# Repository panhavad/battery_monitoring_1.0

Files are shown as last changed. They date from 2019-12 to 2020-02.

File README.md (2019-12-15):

# Battery Monitoring 1.0 for Network's Antenna

In order to get internet connection to supply the whole vKirirom resort, network department is totally dependent on internet signal received by an antenna placed on the top of the mountain which can not supply electricity there by wire. So network department decided to use solar panel and battery but there were certain problem that cause the lost of internet supply to vKirirom such as Battery is empty without knowing. So this project is created to solve that problem by monitoring the battery power remotely.

**During the initial creation of the Network Battery Monitoring V1.0 we are targeting a specific goal to achieve in this version such as:**
1. Live monitoring of each battery power
2. Alert to the responsible person when the battery power reaches a certain level
3. Able to transfer battery information through ethernet
4. 60% of the programming configuration should be able to customize through network.

Finally, after all the hard work, and the help from network department team. I am able to understand what the problem is, what they need, and what are all the constraints I have to handle during do the project. On 12 October 2019 Network Battery Monitoring V1.0 was indoor tested and satisfy by Mr.Nget Phanny.

Yours Truly,
Duk Panhavad

### Hardware usage

- Arduino UNO (Chiness Version)
- Arduino Ethernet Shield W5100
- Customize Series Voltage Divider

## Series Voltage Divider Schema
Series Voltage Divider Schema

## Whole Circuit Connection
Whole Circuit Connection

## Case Modeling
Case Modeling

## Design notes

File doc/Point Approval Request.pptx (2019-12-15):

## Network’s Battery Monitoring

Dexpertize Virtual Company

## Problems

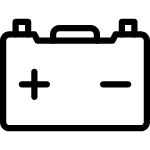
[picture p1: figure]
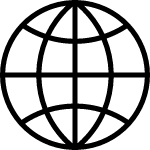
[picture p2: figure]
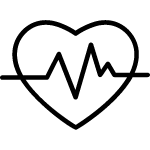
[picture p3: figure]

Running out of battery without knowing

Increase internet downtime

Battery health is unknown

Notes: Running out of battery without knowing
Increase internet down time
Battery health is unknown (identify the infection)

## Solutions / Objectives

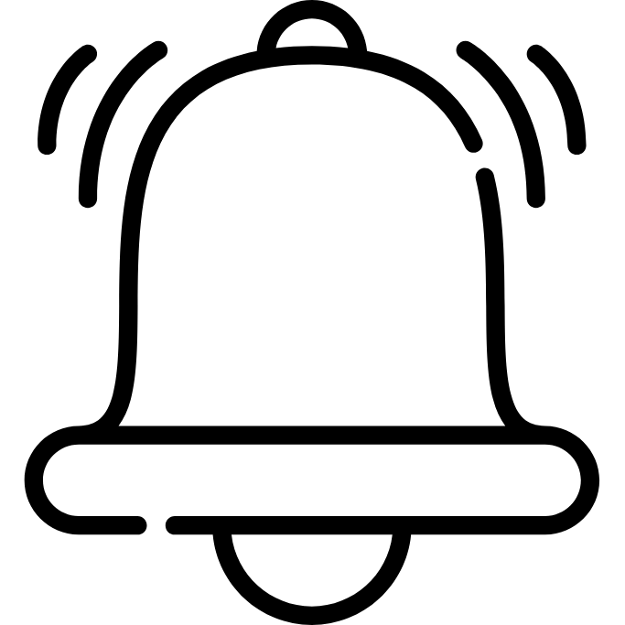
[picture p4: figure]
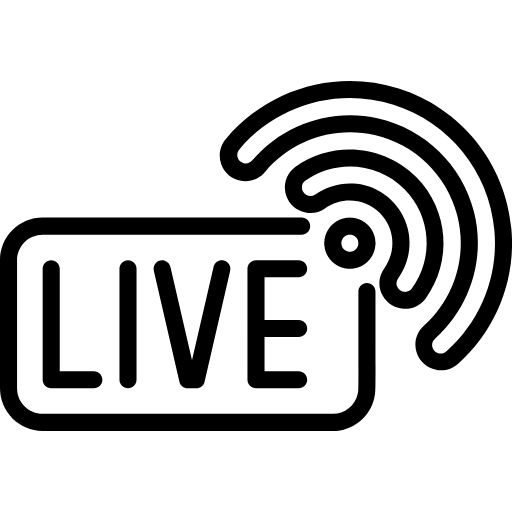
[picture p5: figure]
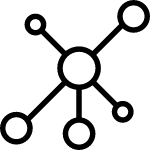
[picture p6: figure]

Notify when battery running low

Live monitor battery Voltage

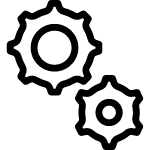
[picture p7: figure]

Work within local-network

Threshold & Alert Interval Configuration can done on app/web

## Output (Software)

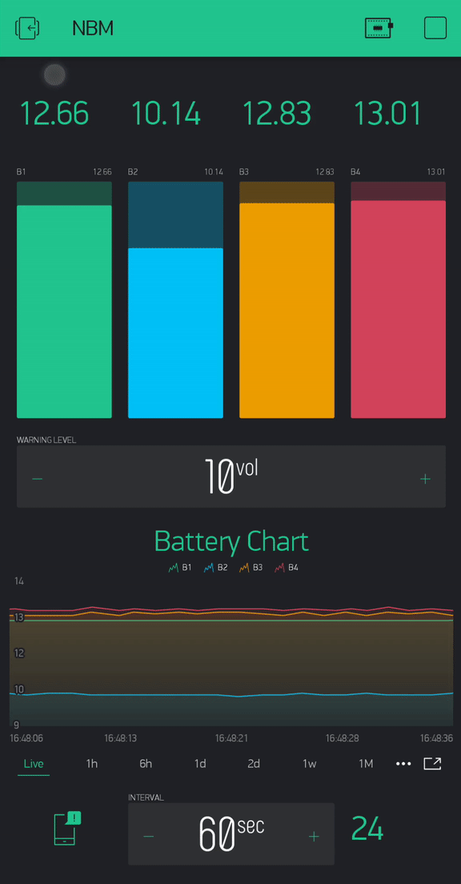
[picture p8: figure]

Live monitor battery Voltage

Voltage Threshold for alert

Battery voltage histogram

Alert interval in second

## Output (Software)

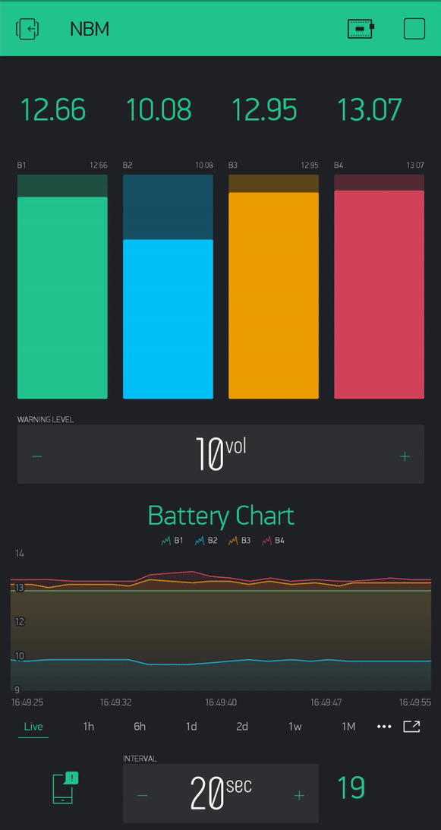
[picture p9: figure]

Alert / Notification when battery reach threshold

## Output (Hardware)

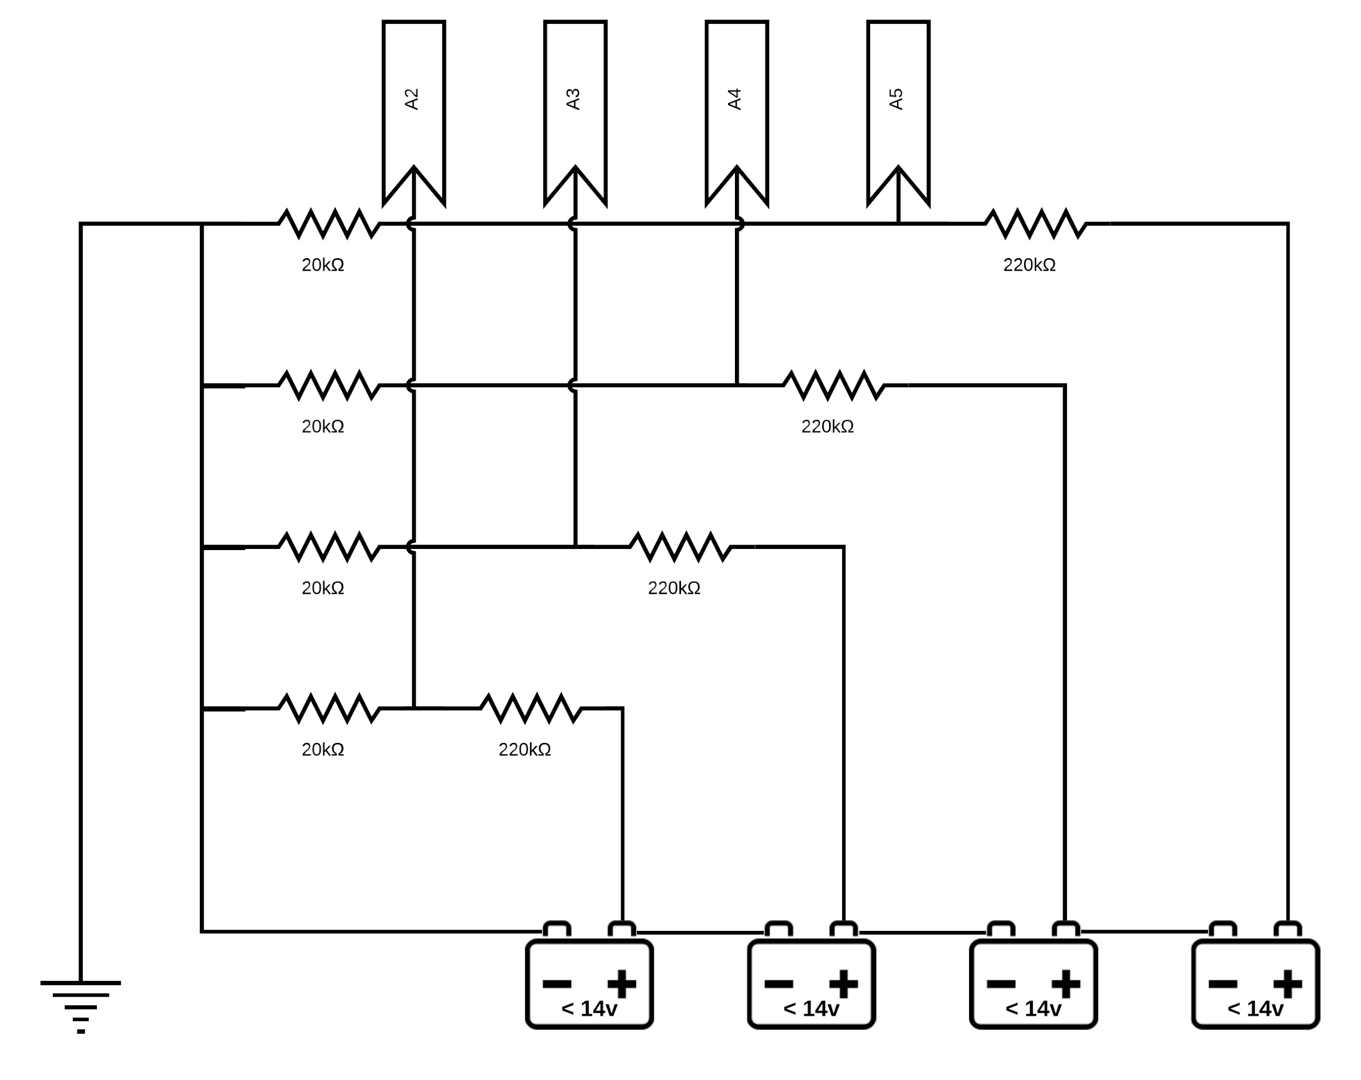
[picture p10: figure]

Voltage divider for Series of battery

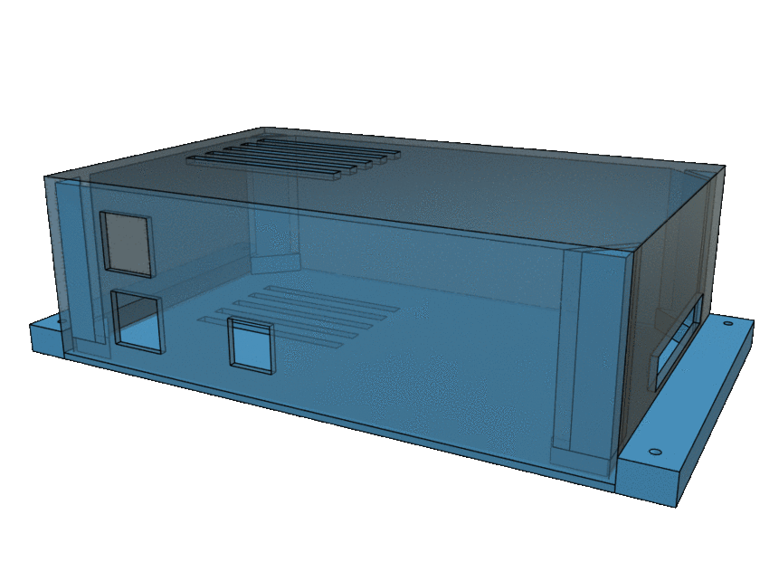
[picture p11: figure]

3D Printed Case (KIT)

## Cost of Production

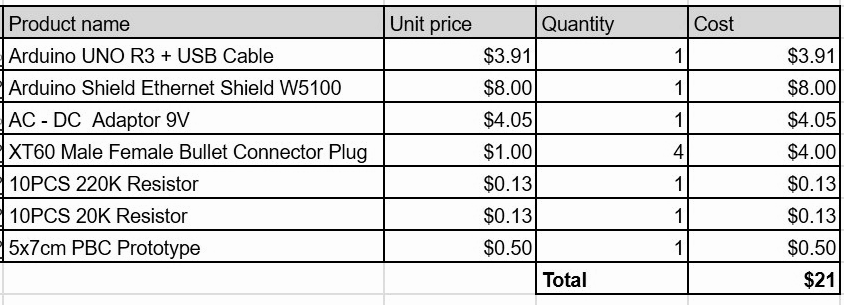
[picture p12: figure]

## Demo

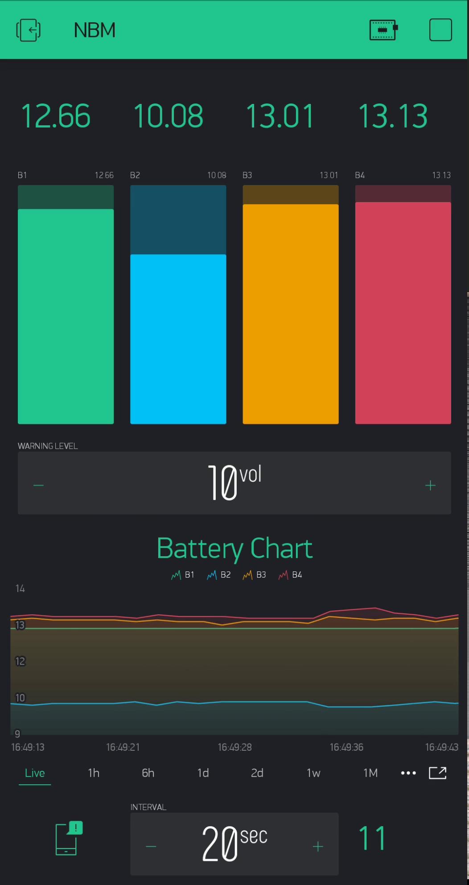
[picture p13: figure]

## Mr.Takeshi Remark

This project is successfully closed and approve 10 KIT Point

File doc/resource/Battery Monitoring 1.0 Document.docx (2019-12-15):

# Network Battery Monitoring(NBM) Document

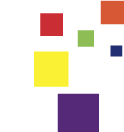
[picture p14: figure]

# Version 1.0

### DEVELOPED BY

DUK PANHAVAD (BATCH3)

# Table of Contents

Introduction 3

Document Purpose 3

Scope of document 3

Definitions, acronyms, and abbreviations 3

References Document 3

Hardware overview 4

Hardware usage 4

Voltage Divider Circuit 4

Hardware case 5

Software overview 6

Use-Case diagram 6

Cost of Production 7

Project Output 7

Network Battery Monitoring V1.0

JUN 27, 2019

### COMPANY - Dexpertize

### Projects - Network Battery Monitoring V1.0

Members:

Duk Panhavad

This is written to make understand of how this project created.

In order to get internet connection to supply the whole vKirirom resort, network department is totally dependent on internet signal received by an antenna placed on the top of the mountain which can not supply electricity there by wire. So network department decided to use solar panel and battery but there were certain problem that cause the lost of internet supply to vKirirom such as Battery is empty without knowing. So this project is created to solve that problem by monitoring the battery power remotely.

During the initial creation of the Network Battery Monitoring V1.0 we are targeting a specific goal to achieve in this version such as:

- Live monitoring of each battery power
- Alert to the responsible person when the battery power reaches a certain level
- Able to transfer battery information through ethernet
- 60% of the programming configuration should be able to customize through network.

Finally, after all the hard work, and the help from network department team. I am able to understand what the problem is, what they need, and what are all the constraints I have to handle during do the project. On 12 October 2019 Network Battery Monitoring V1.0 was indoor tested and satisfy by Mr.Nget Phanny.

Yours Truly,

Duk Panhavad

# 1. Introduction

This section gives a scope, description and overview of everything have to be done in this project.

## 1.1. Document Purpose

The purpose of this document is to give a detailed description of the requirements for the “Network Battery Monitoring”. It will illustrate the purpose and complete declaration for the development of system. It will also explain system constraints, interface and interactions with other external applications. This document is primarily intended to be a reference for developing the first version of the system for the developer.

## 1.2. Scope of document

From the very beginning, the lost of battery power at anata without knowing in advance cause so much problem to vKirirom Staff, Student, Customer and Security. So this project will be so helpful to solve those problems.

By notifying the responsible person in advance before those batteries run empty. This will be so useful for battery replacing problem since currently if the battery runs empty it might take nearly 3hours to prepare everything and fully replace those batteries.

While the responsible get notify in advance, any action that will have to perform in order to change the battery will be prepare in advance too. So this will bring vKirirom internet to 99.99% downtime.

## 1.3. Definitions, acronyms, and abbreviations

- NBM - Network Battery Monitoring
- Arduino UNO - is an open-source microcontroller board based on the Microchip ATmega328P microcontroller and developed by Arduino.cc
- Arduino Ethernet Shield - allows an Arduino board to connect to the internet
- Blynk - IoT platform to connect your devices to the cloud, design apps to control them, analyze telemetry data, and manage your deployed products at scale

## 1.4. References Document

- https://www.arduino.cc
- https://blynk.io

# 2. Hardware overview

## 2.1. Hardware usage

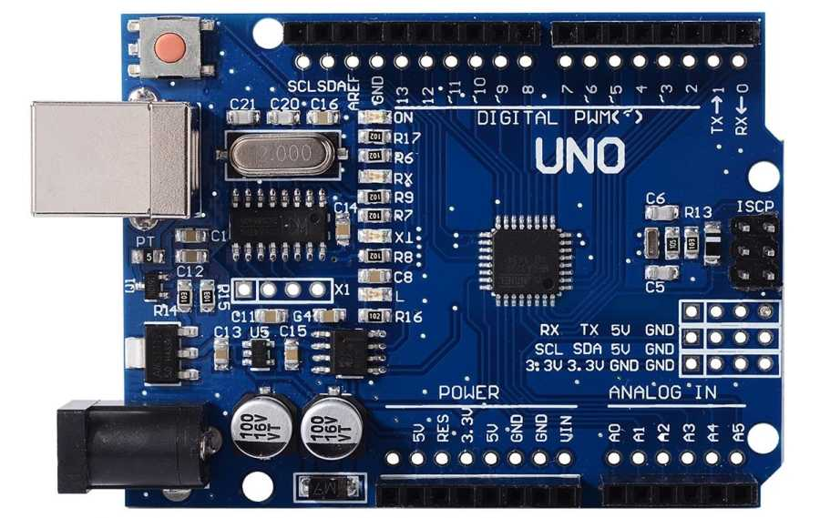
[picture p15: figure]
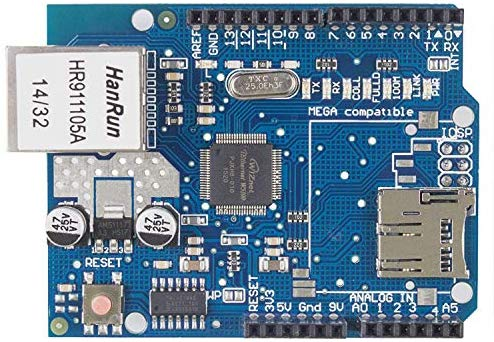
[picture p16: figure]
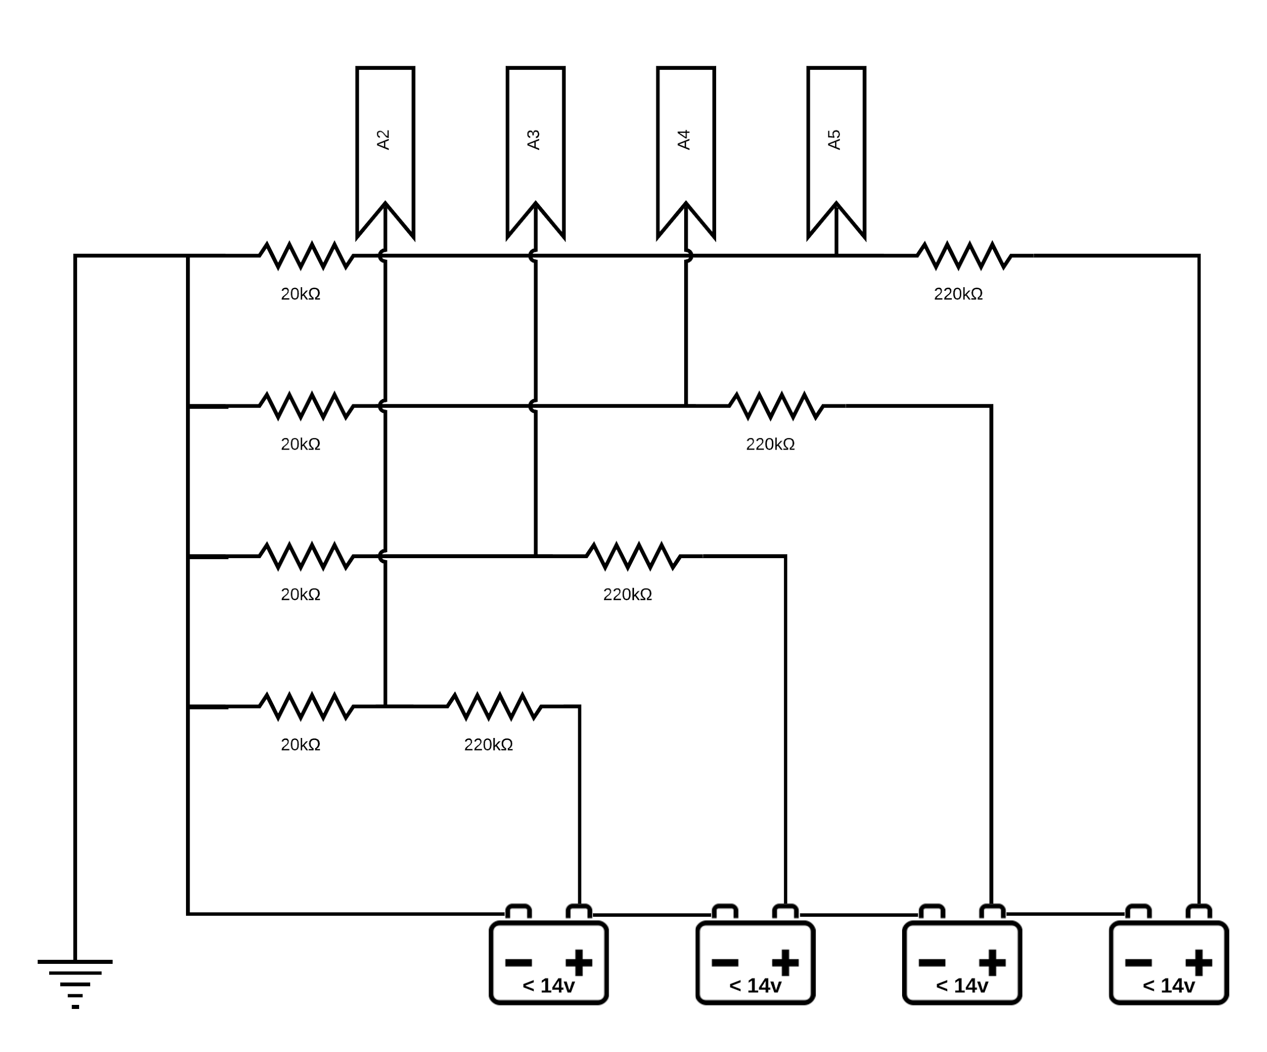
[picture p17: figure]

- Arduino UNO (Chiness Version)
- Arduino Ethernet Shield W5100
- Customize Series Voltage Divider

## 2.2. Voltage Divider Circuit

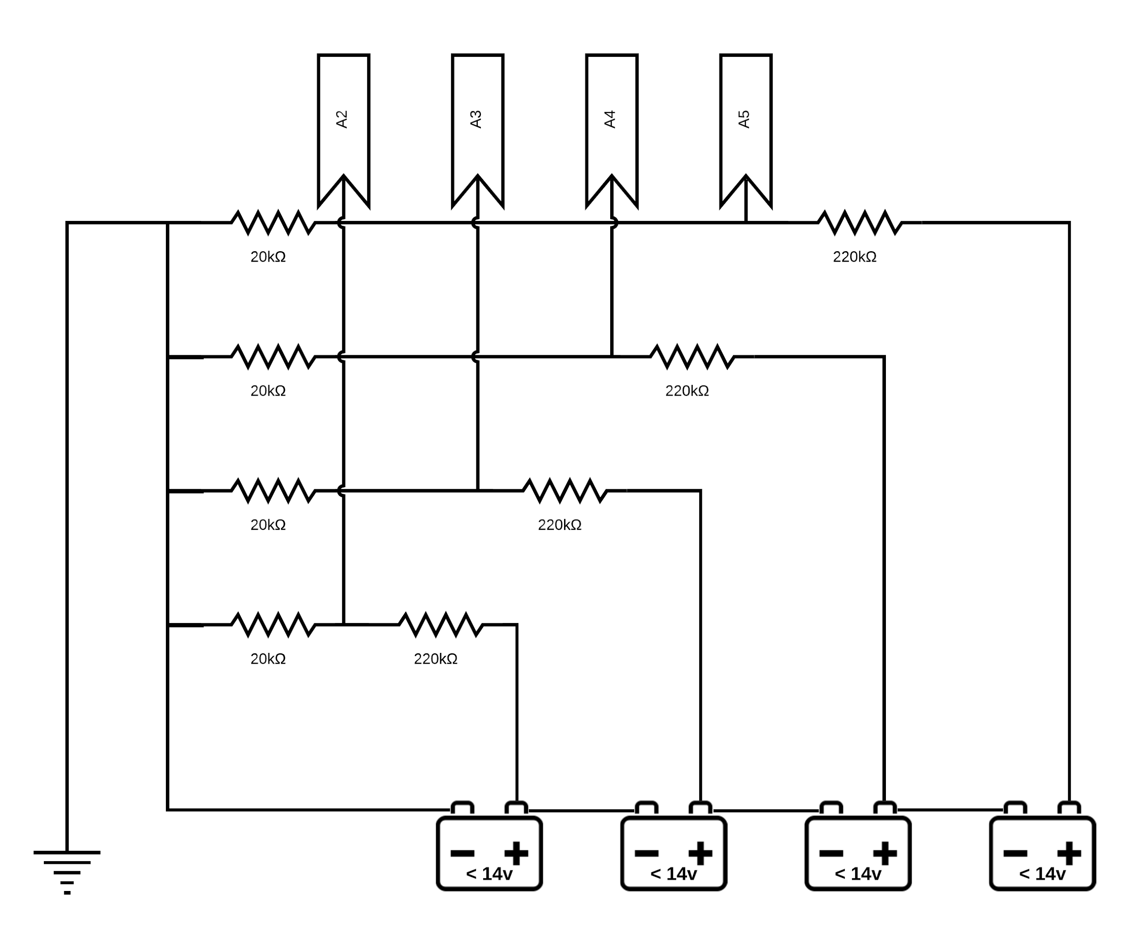
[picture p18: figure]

  2.3. Circuit Connection

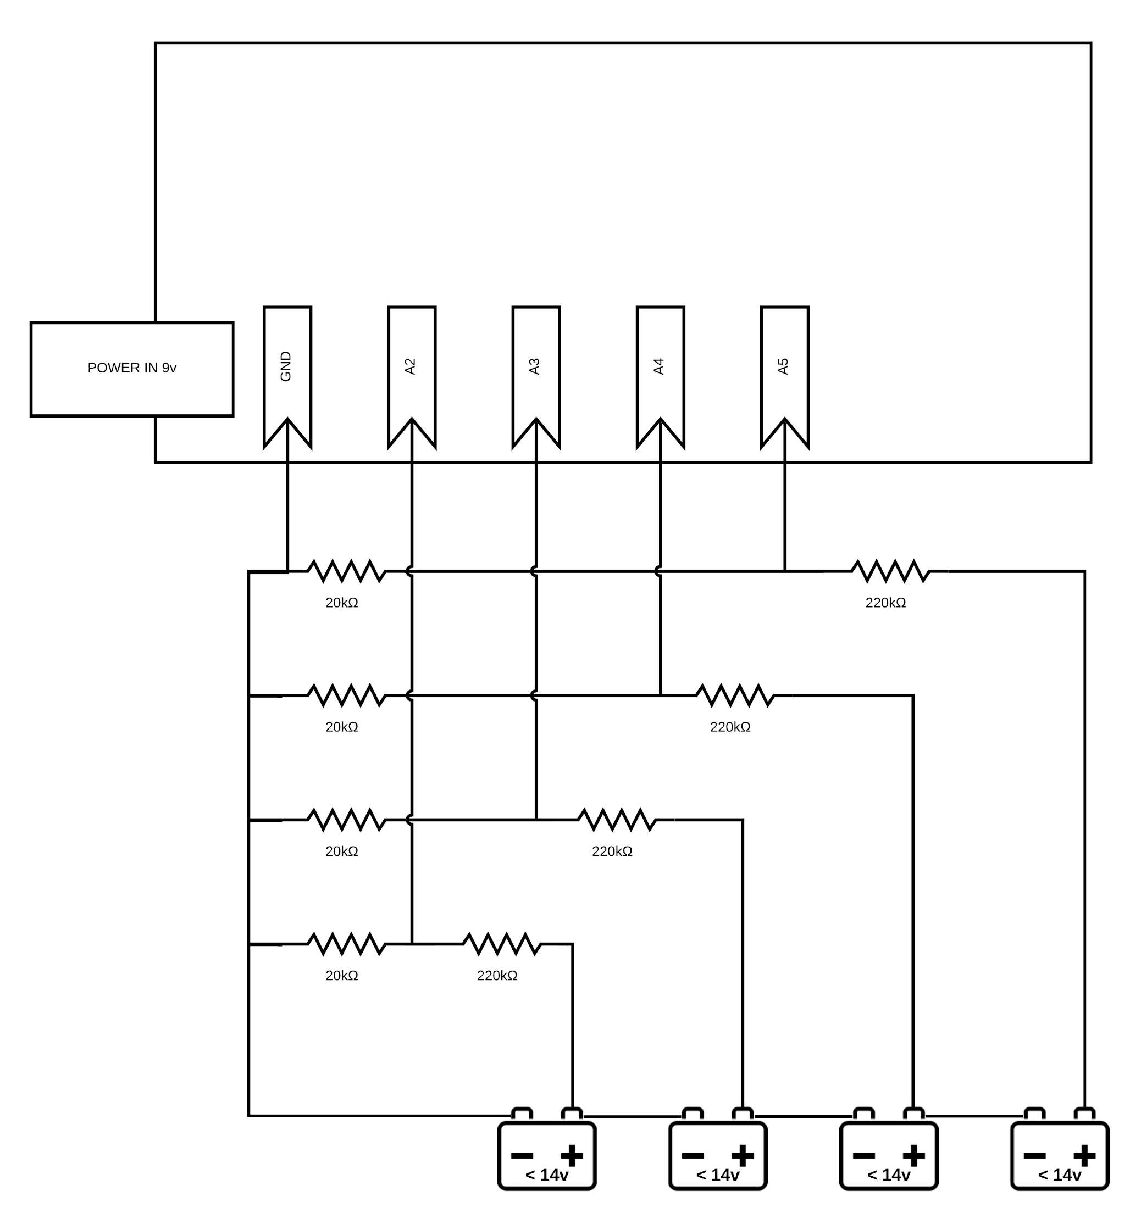
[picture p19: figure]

## 2.4. Hardware case

Link to 3D model: case_modeling (https://drive.google.com/drive/folders/1mzTB_Wjy93GVwVte1kKjALP6ZSL0zM3l)

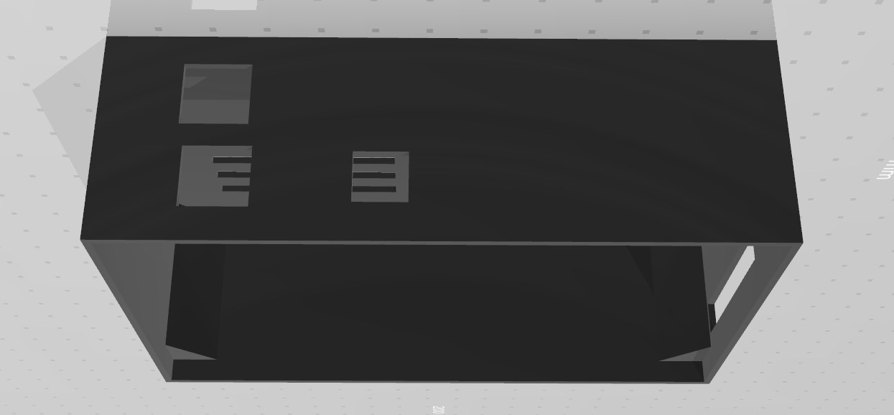
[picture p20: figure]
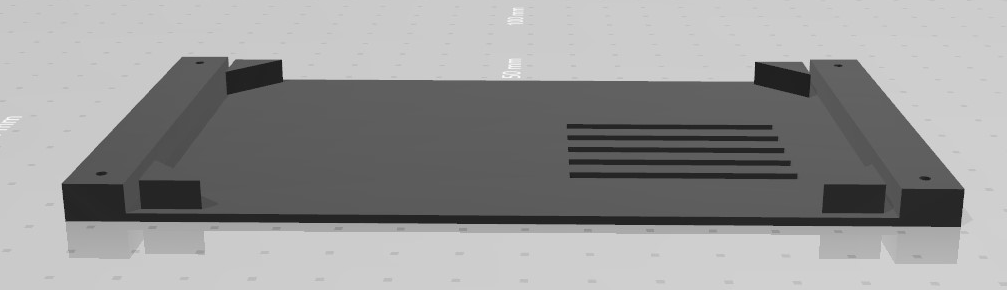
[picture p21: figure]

# 3. Software overview

  3.1. Software Usage

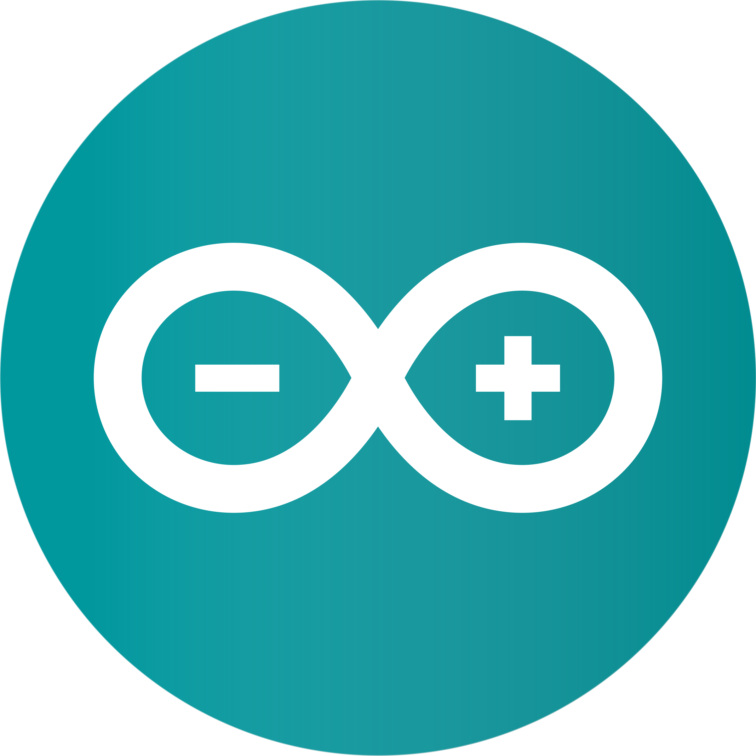
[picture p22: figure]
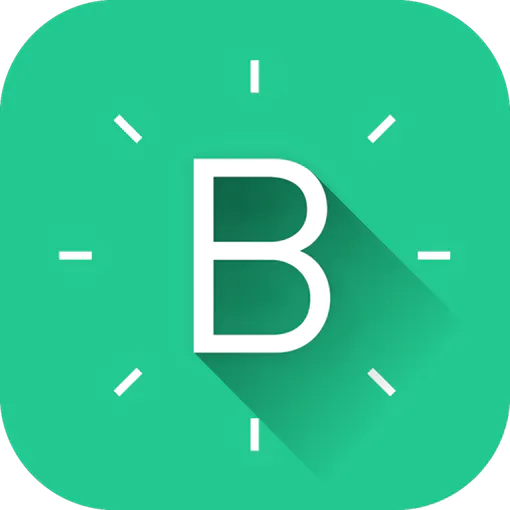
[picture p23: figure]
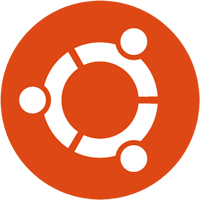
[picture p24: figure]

- Arduino IDE (Free)
- Blynk App (Free)
- Blynk Local Server (Free)

## 3.2. Use-Case diagram


  3.3. Source Code (Private)

Link to GitHub Repository: https://github.com/panhavad/network_battery_monitoring

# 4. Cost of Production


# 5. Project Output


Kirirom Institute of Technology Network Battery Monitoring 1.0

Kirirom Institute of Technology KIT Key Management System 1.0

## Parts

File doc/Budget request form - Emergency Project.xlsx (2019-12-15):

 | Budget Request Form
Company name: | Dexpertize
Project name: | Network Antenna Battery Monitoring
Project member: | Duk Panhavad
Request by: | Duk Panhavad
Reason of emergency: | The project is process during holiday, product is cheap, less quantity
Project Approve by: | Mr.Leo
Budget Approve by: | Mr.Leo
*NOTE: This document is use for request the budget, because project spend there own money to buy these listed product for the project. This is not request for purchase.
Link | Product name | Unit price | Quantity | Cost
https://www.aliexpress.com/item/32697443734.html | Arduino UNO R3 + USB Cable | $3.91 | 1 | $3.91
http://store.arrowdot.io/?product=arduino-shield-ethernet-shield-w5100 | Arduino Shield Ethernet Shield W5100 | $8.00 | 1 | $8.00
https://www.aliexpress.com/item/32961533195.html | AC - DC Adaptor 9V | $4.05 | 1 | $4.05
http://store.arrowdot.io/?product=xt60-male-female-bullet-connector-plug-for-lipo-battery-rc-drone | XT60 Male Female Bullet Connector Plug | $1.00 | 4 | $4.00
http://store.arrowdot.io/ | 10PCS 220K Resistor | $0.13 | 1 | $0.13
http://store.arrowdot.io/ | 10PCS 20K Resistor | $0.13 | 1 | $0.13
http://store.arrowdot.io/?product=5x7cm-single-side-diy-bakelite-prototype-circuit-pcb-board-tinned | 5x7cm PBC Prototype | $0.50 | 1 | $0.50
 |  |  | Total | $20.72

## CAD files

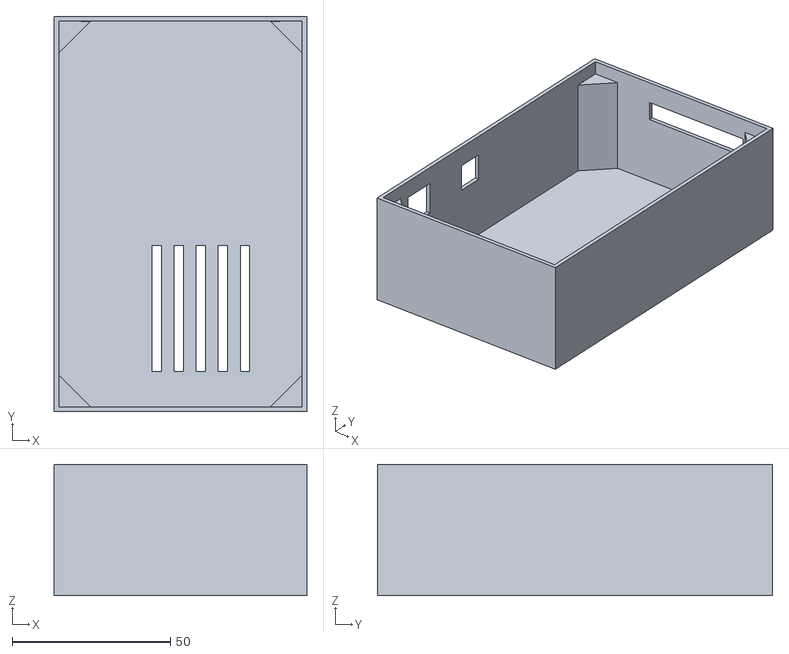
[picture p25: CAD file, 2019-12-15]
case_modeling/top.stl
80.0 x 125.0 x 41.5

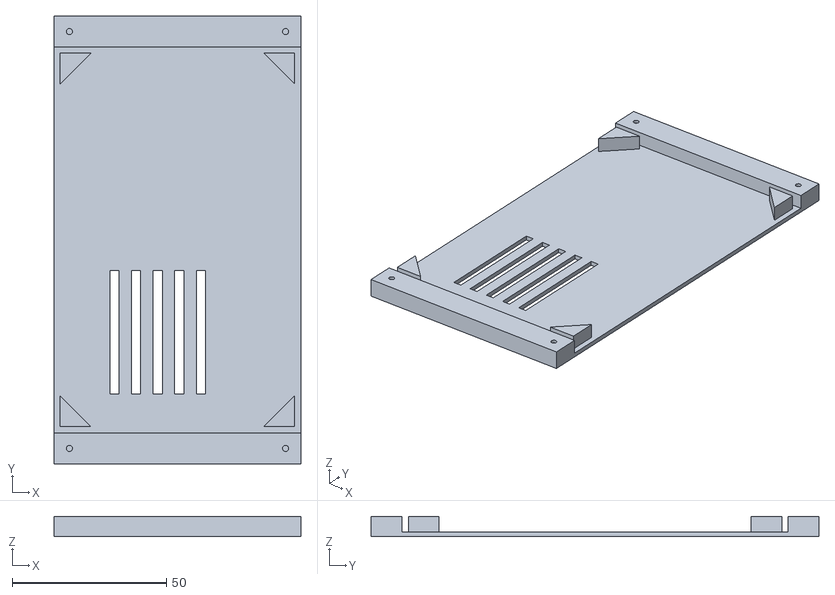
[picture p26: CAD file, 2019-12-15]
case_modeling/bottom.stl
80.0 x 145.0 x 6.50

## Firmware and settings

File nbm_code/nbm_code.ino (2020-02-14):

/////////////////////////
// AUTHOR : AHIRU SAN  //
// DATE : 01 NOVE 2019 //
/////////////////////////


//hardware related
#include <SPI.h> //library for ethernet shield
#include <Ethernet.h> //library for ethernet shield
#include <BlynkSimpleEthernet.h> //BLYNK communication using ethernet
#include <EEPROM.h> //memory that store data even restart

//BLYNK related
#define WARNING_VOL_LEVEL_PIN V5
#define WARNING_INTERVAL_PIN V6

//asyncronization related
#define samplingInterval 20
#define printInterval 1000
#define sampleLoad 50

//arduino ethernet shield related
#define W5100_CS  10
#define SDCARD_CS 4


float R1 = 220000.0; //first resistor value on voltage devider
float R2 = 20000.0; //second resistor value on voltage devider

float voltage_in_res[4]; //array of calculated voltage massure from battery (final result)
int analog_value_origin[4]; //array of raw analog value from arduino pin 0 - 1024 (series massurement)
int analog_value_calculated[4]; //array of raw analog value calculated isolate the messurement from series
int analog_pin[] = {16, 17, 18, 19}; //array of analog pin that are using (A2 - A5)
int arr_pin_len = sizeof(analog_pin)/sizeof(int); //len of the array analog pin
int virtual_battery_pin[] = {V0, V1, V2, V3}; //array of battery pin in BLYNK

int warning_interval_counter = 0; //counter when condition of warning matched
int warning_interval_value = 10; //warning counter set, will be change by user in BLYNK
int warning_voltage_level = 0; //voltage of each battery that set for warning (minimum)
int start_indicator = 1; //indicator that said the board is just start power on

//BLYNK server configuration
// char auth[] = "dNLW3Q96qY_M4Em16CHrQiU6Sz0S4lAA"; //BLYNK project token
IPAddress server_ip (10, 254, 253, 13); //BLYNK server IP

//arduino ethernet confirguration (network)
byte arduino_mac[] = { 0xDE, 0xED, 0xBA, 0xFE, 0xFE, 0xED }; // MAC address should be different for each device in your LAN
IPAddress arduino_ip ( 10,   0,   16,  11); //static IP for this arduino
IPAddress dns_ip     (  8,   8,   8,   8);
IPAddress gateway_ip ( 10,   0,   0,   1);
IPAddress subnet_mask(255, 0, 0, 0);


void setup() {

  for (int i = 0; i < arr_pin_len; i += 1) {
    //enable reading mode on analog pin
    pinMode(analog_pin[i], INPUT);
  }

  Serial.begin(9600); //enable serial mode on bitrate at 9600

  //some conflict in BLYNK configuration so have to place raw token string here
  Blynk.begin("lWoWHfQ-jUH0byk8DzUCwbeDhay-OCp2", server_ip, 8080, arduino_ip, dns_ip, gateway_ip, subnet_mask, arduino_mac); //establish connection to BLYNK server

}

BLYNK_WRITE(V5) {
  //gets the value stored in V5 as an integer
  warning_voltage_level = param.asInt();
}

BLYNK_WRITE(V6) {
  //gets the value stored in V2 as an integer 
  warning_interval_value = param.asInt(); 
}

void loop() {

  //timing variable for asyncronus execution
  static unsigned long samplingTime = millis(); //sample processing time
  static unsigned long printTime = millis(); //print or output time
  
  Blynk.run(); //start BLYNK communication

  if (start_indicator == 1) { //is this board just power up?
    warning_voltage_level  = EEPROM.read(0); //read value from EEPROM on address 0
    warning_interval_value = EEPROM.read(1); //read value from EEPROM on address 1
    
    //write the value that get from EEPROM to BLYNK
    Blynk.virtualWrite(WARNING_VOL_LEVEL_PIN, warning_voltage_level);
    Blynk.virtualWrite(WARNING_INTERVAL_PIN, warning_interval_value);
    
    start_indicator = 0; //reset board state
  }
  
  //read data from analog pin from A2 - A5
  for (int i = 0; i < arr_pin_len; i += 1) {
    analog_value_origin[i] = analogRead(analog_pin[i]); //orginal value raw from alanalog pin
  }

  //find the arverage from 20 collected samples value
  for (int i = 0; i < arr_pin_len; i++ ) {

    for (int i_pin = 0; i_pin < arr_pin_len; i_pin++) {
      int buffer[sampleLoad], temp; //buffer, temp ready for ordering value in order
      unsigned long int avgValue; //final result of the loop (arverage value of 20 samples)

        //read data raw data from analog pin 0 - 1024
        for (int i = 0; i < sampleLoad; i++) {
          buffer[i]=analogRead(analog_pin[i_pin]); //read 20 times of value on only one pin (getting sample)
        }
        
        //ordering the collected sameple in ASC order
        for (int i = 0; i < sampleLoad - 1; i++) {
          for (int j=i+1;j<sampleLoad;j++) {
            if (buffer[i]>buffer[j]) {
              temp=buffer[i];
              buffer[i]=buffer[j];
              buffer[j]=temp;
            }
          }
        } //ordering done     
      
      avgValue = 0; //make sure that the initail average value is 0

      //ignore the first 5 small value then sum the rest together
      for (int i = 5; i < sampleLoad - 5; i++) {
        avgValue+=buffer[i]; //sum each buffer value together
      }
      analog_value_origin[i_pin]=(float)avgValue/(sampleLoad - 10); //find the average result
    }
  
    //isolate the the massurement value from series connection & and refine the value
    if (i == 0) {//if one first battery value
      analog_value_calculated[i] = analog_value_origin[i]; //value dont change
    }else if (i == 3) {//if the one last battery value
      analog_value_calculated[i] = analog_value_origin[i] - analog_value_origin[i - 1] - 20; //throught out the whole massurement there are at most 20 raw value extra
    }else {
      analog_value_calculated[i] = analog_value_origin[i] - analog_value_origin[i - 1]; //isolate the massurement value for only one spacific battery
    }
    //ensure the final value is not exit what we expect
    analog_value_calculated[i] >= 239 ? analog_value_calculated[i] = 239 : analog_value_calculated[i] = analog_value_calculated[i]; //if the value exit 240 analog value
    analog_value_calculated[i] <= 0 ? analog_value_calculated[i] = 0 : analog_value_calculated[i] = analog_value_calculated[i]; //if the value lower them 0 analog value
  }
  //sample processing timer
  if (millis() - samplingTime > samplingInterval) {
    
    for (int i = 0; i < arr_pin_len; i += 1) {
      voltage_in_res[i] = voltageCalculation(analog_value_calculated[i]); //convert from raw analog input to voltage
    }

    samplingTime = millis(); //reset timer
  }

  //output timer
  if (millis() - printTime > printInterval) {//Every 800 milliseconds, print a numerical, convert the state of the LED indicator
    
    //DEBUG
    // for (int i = 0; i < arr_pin_len; i += 1) {
    //   Serial.print("ANALOG -- ");
    //   Serial.print(i + 16);
    //   Serial.print(" Voltage: ");
    //   Serial.println(voltage_in_res[i],2);
    // }

    //update the current value to EEPROM
    EEPROM.update(0, warning_voltage_level);
    EEPROM.update(1, warning_interval_value);

    //write value of the massured voltage of each battery of each battery vitual pin in BLYNK
    for (int i = 0; i < arr_pin_len; i += 1) {
      Blynk.virtualWrite(virtual_battery_pin[i], voltage_in_res[i]); //write to voltage value to virtual pin
    }

    Blynk.virtualWrite(V4, warning_interval_counter); //write warning counter to BLYNK virtual pin V4

    float minVol = getMin(voltage_in_res, arr_pin_len); //find the minimum voltage value among all batteries
    
    //validate the current voltage and minimum 
    if (minVol <= warning_voltage_level) {
      warning_interval_counter += 1;
        if (warning_interval_counter == warning_interval_value) { // when the counter reach the limit
          Blynk.notify("Battery is warning, Please check!"); //send warning to app
          warning_interval_counter = 0; //reset the counter
        }
      }else{
        warning_interval_counter = 0; //reset the counter
      }
      
      printTime = millis(); //reset timer
    }
}

//convert raw analog value to voltage
float voltageCalculation(float value) {
  float calculation_result = 0.0, voltage_output = 0.0;
  
  voltage_output = (value * 5.0) / 1024.0; //devider base on the voltage of the arduino
  calculation_result = voltage_output / (R2/(R1+R2)); //voltage devider
  
  return calculation_result;
}

//find the minimum voltage value
float getMin(float* array, int size) {
  int minimum = array[0];

  for (int i = 0; i < size; i++) {
    if (array[i] < minimum) {
      minimum = array[i];
    }
  }
  return minimum;
}
